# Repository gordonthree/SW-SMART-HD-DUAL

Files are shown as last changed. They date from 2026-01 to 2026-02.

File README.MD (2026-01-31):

# Heavy Duty Dual Smart Switch Node

Compact power distribution module intended to control two heavy duty high-side DC loads. The module provides eFuse protection and current monitoring for each load. Module temperature and supply voltage are also monitored. This module works with other CAN-CTL modules using the robust CAN bus interface.

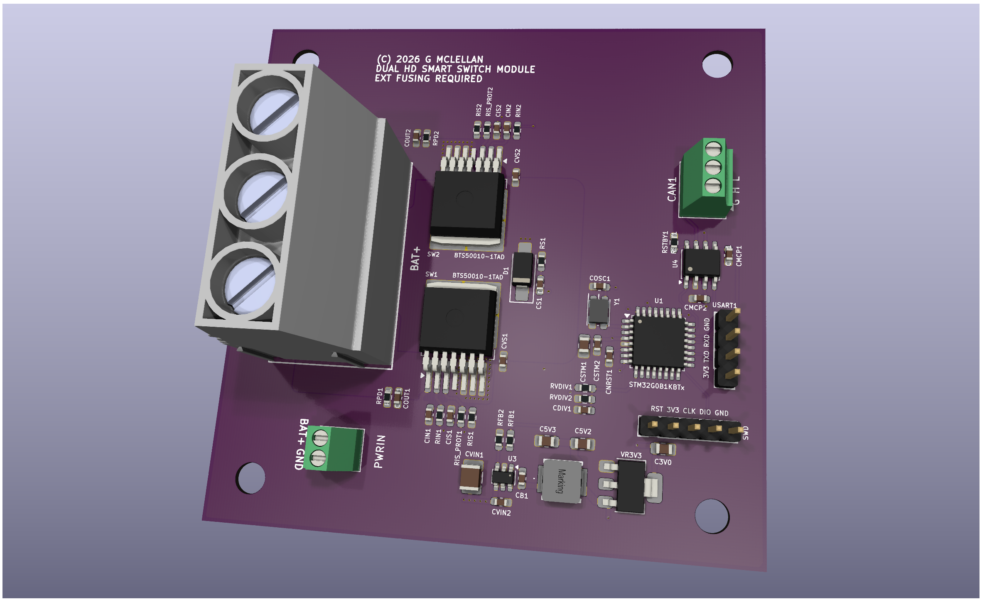
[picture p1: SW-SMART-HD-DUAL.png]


* STM32G0B1KBT 32-pin microcontroller on board
* Dual Infineon BTS50010 Profet smart switches for high side loads
* Microchip MCP2562 isolated CAN bus transceiver
* Voltage divider to monitor supply voltage
* High side switch current monitoring and diagnostics
* Three position screw terminal block for CAN bus connection
* Heavy duty terminal block connectors for power in/out
* Headers for SWD programming and USART1 debug serial port

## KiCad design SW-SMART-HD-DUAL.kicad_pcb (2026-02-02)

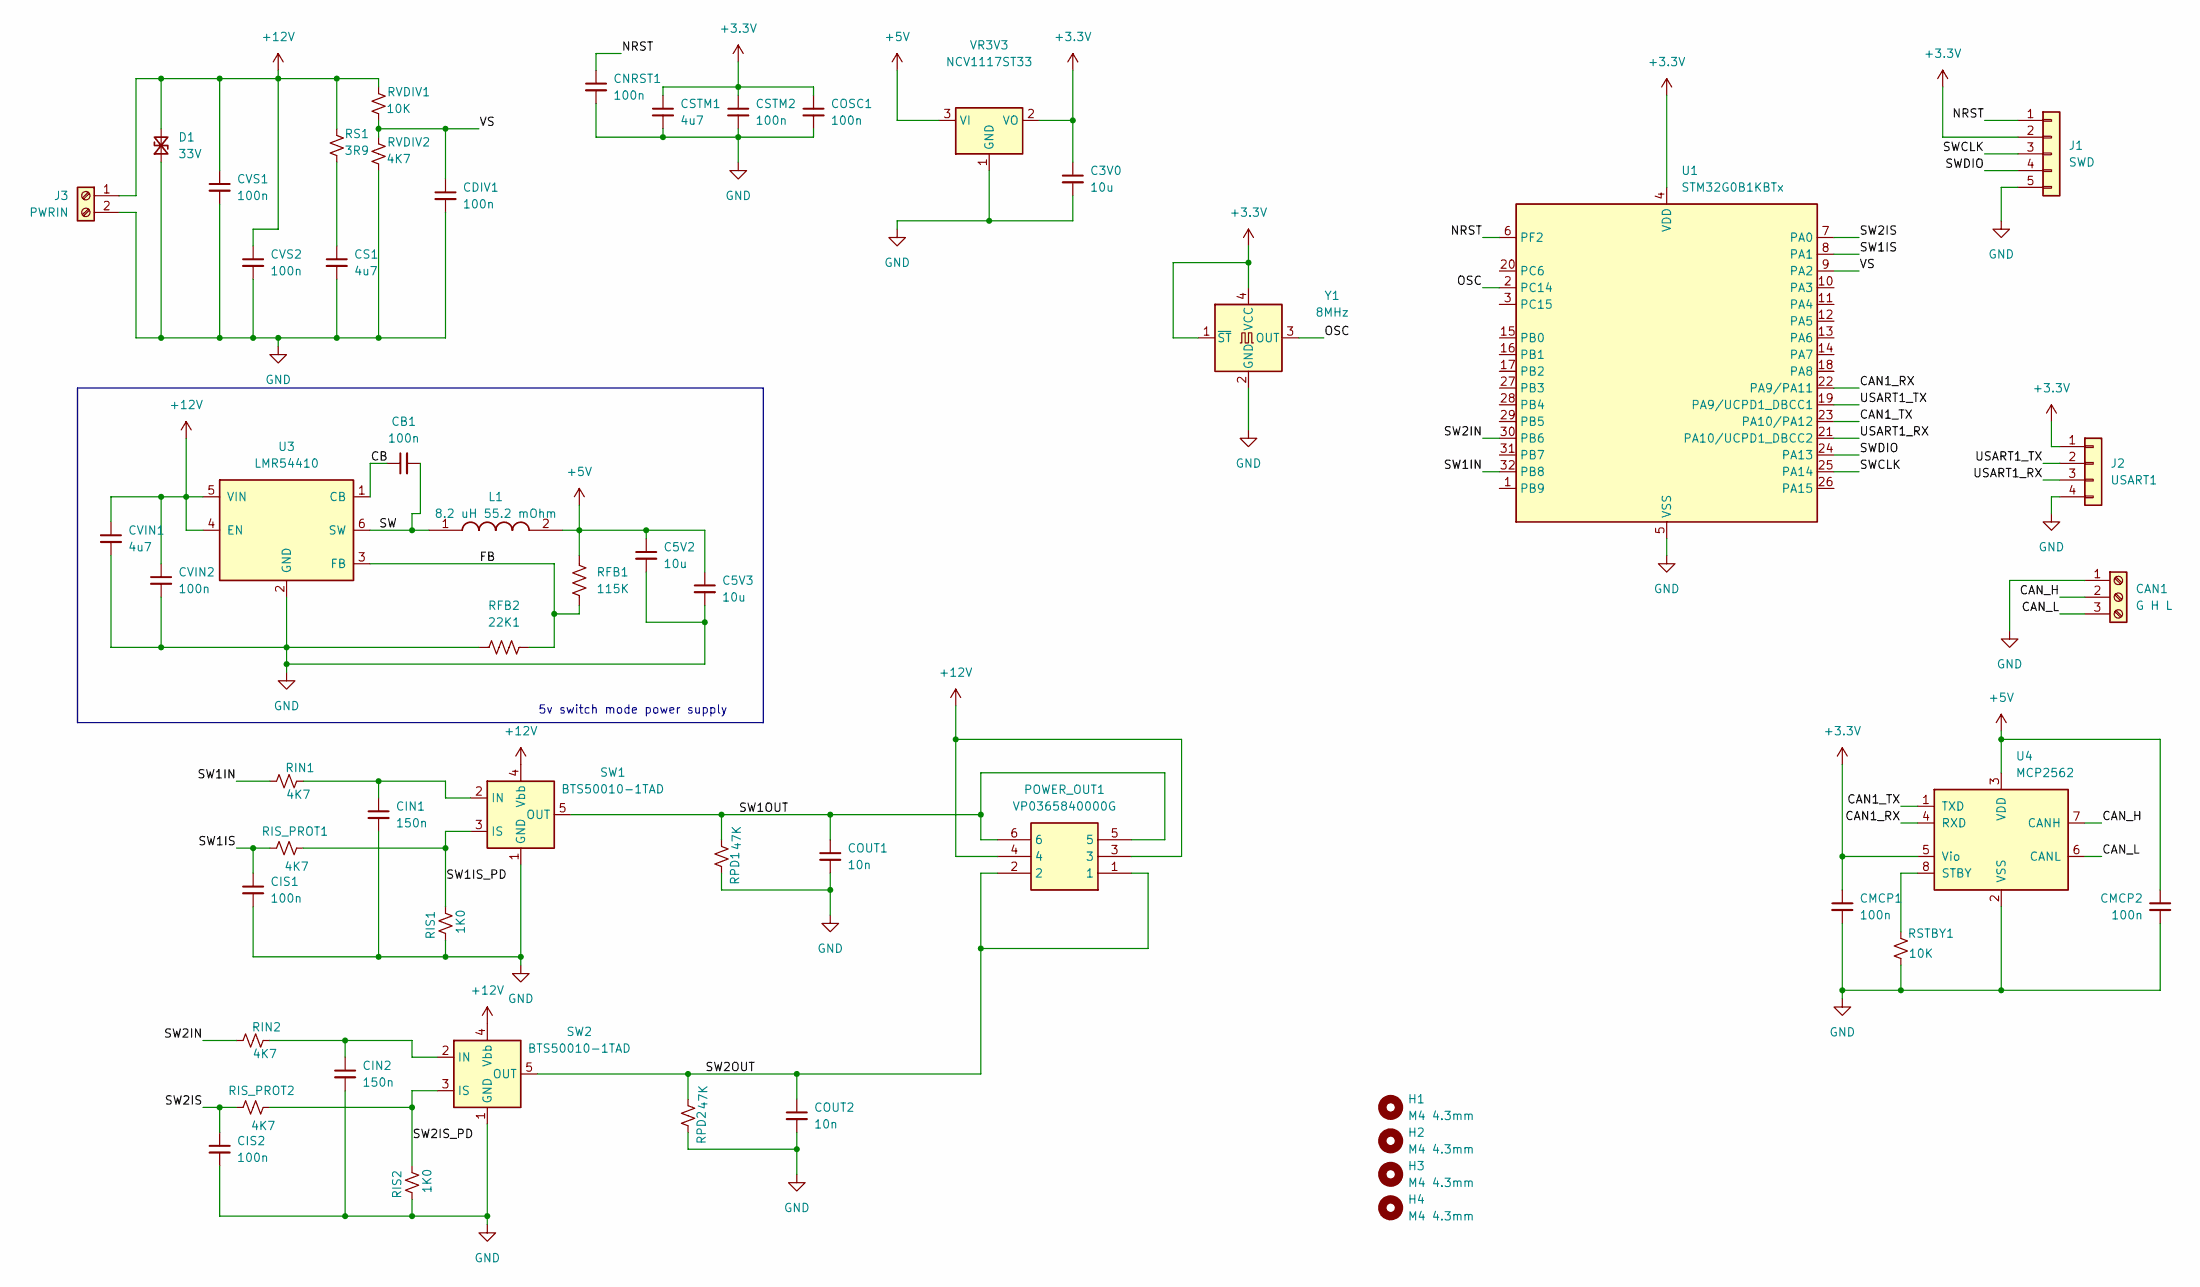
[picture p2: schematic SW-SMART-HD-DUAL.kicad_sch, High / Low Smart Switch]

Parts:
C3V0, C5V2, C5V3: 10u; C_0805_2012Metric_Pad1.18x1.45mm_HandSolder
CAN1: G H L; TerminalBlock_Phoenix_MPT-0,5-3-2.54_1x03_P2.54mm_Horizontal
CB1: 100n; C_0603_1608Metric_Pad1.08x0.95mm_HandSolder
CDIV1: 100n; C_0603_1608Metric_Pad1.08x0.95mm_HandSolder
CIN1, CIN2: 150n; C_0603_1608Metric_Pad1.08x0.95mm_HandSolder
CIS1, CIS2: 100n; C_0603_1608Metric_Pad1.08x0.95mm_HandSolder
CMCP1, CMCP2: 100n; C_0603_1608Metric_Pad1.08x0.95mm_HandSolder
CNRST1: 100n; C_0603_1608Metric_Pad1.08x0.95mm_HandSolder
COSC1: 100n; C_0603_1608Metric_Pad1.08x0.95mm_HandSolder
COUT1, COUT2: 10n; C_0603_1608Metric_Pad1.08x0.95mm_HandSolder
CS1: 4u7; C_0603_1608Metric_Pad1.08x0.95mm_HandSolder
CSTM1: 4u7; C_0805_2012Metric_Pad1.18x1.45mm_HandSolder
CSTM2: 100n; C_0603_1608Metric_Pad1.08x0.95mm_HandSolder
CVIN1: 4u7; C_1210_3225Metric_Pad1.33x2.70mm_HandSolder
CVIN2: 100n; C_0603_1608Metric_Pad1.08x0.95mm_HandSolder
CVS1, CVS2: 100n; C_0603_1608Metric_Pad1.08x0.95mm_HandSolder
D1: 33V; D_SMA_Handsoldering
H1, H2, H3, H4: M4 4.3mm; MountingHole_4.3mm_M4
J1: SWD; PinHeader_1x05_P2.54mm_Vertical
J2: USART1; PinHeader_1x04_P2.54mm_Vertical
J3: PWRIN; TerminalBlock_Phoenix_MPT-0,5-2-2.54_1x02_P2.54mm_Horizontal
L1: 8.2 uH 55.2 mOhm; SRP5030HMT2R2M; Mouser Part Number SRP5030HMT-8R2M
POWER_OUT1: VP0365840000G; Mouser Part Number 649-VP03658400J0G
RFB1: 115K; R_0603_1608Metric_Pad0.98x0.95mm_HandSolder
RFB2: 22K1; R_0603_1608Metric_Pad0.98x0.95mm_HandSolder
RIN1, RIN2: 4K7; R_0603_1608Metric_Pad0.98x0.95mm_HandSolder
RIS1, RIS2: 1K0; R_0603_1608Metric_Pad0.98x0.95mm_HandSolder
RIS_PROT1, RIS_PROT2: 4K7; R_0603_1608Metric_Pad0.98x0.95mm_HandSolder
RPD1, RPD2: 47K; R_0603_1608Metric_Pad0.98x0.95mm_HandSolder
RS1: 3R9; R_0603_1608Metric_Pad0.98x0.95mm_HandSolder
RSTBY1: 10K; R_0603_1608Metric_Pad0.98x0.95mm_HandSolder
RVDIV1: 10K; R_0603_1608Metric_Pad0.98x0.95mm_HandSolder
RVDIV2: 4K7; R_0603_1608Metric_Pad0.98x0.95mm_HandSolder
SW1, SW2: BTS50010-1TAD; TO-263-7_TabPin4
U1: STM32G0B1KBTx; LQFP-32_7x7mm_P0.8mm
U3: LMR54410; SOT-23-6
U4: MCP2562; SOIC-8_3.9x4.9mm_P1.27mm
VR3V3: NCV1117ST33; SOT-223-3_TabPin2
Y1: 8MHz; Oscillator_SMD_EuroQuartz_XO32-4Pin_3.2x2.5mm_RotB_HandSold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

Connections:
+3.3V: C3V0.1, CMCP1.1, COSC1.1, CSTM1.1, CSTM2.1, J1.2, J2.1, U1.4 (VDD), U4.5 (Vio), VR3V3.2 (VO), Y1.1 (~ST), Y1.4 (VCC)
+5V: C5V2.1, C5V3.1, CMCP2.1, L1.2, RFB1.1, U4.3 (VDD), VR3V3.3 (VI)
+12V: CVIN1.1, CVIN2.1, CVS1.1, CVS2.1, D1.2 (A2), J3.1, POWER_OUT1.3, POWER_OUT1.4, RS1.2, RVDIV1.2, SW1.4 (Vbb), SW2.4 (Vbb), U3.4 (EN), U3.5 (VIN)
/CAN1_RX: U1.22 (PA9/PA11), U4.4 (RXD)
/CAN1_TX: U1.23 (PA10/PA12), U4.1 (TXD)
/CAN_H: CAN1.2, U4.7 (CANH)
/CAN_L: CAN1.3, U4.6 (CANL)
/CB: CB1.1, U3.1 (CB)
/FB: RFB1.2, RFB2.2, U3.3 (FB)
/NRST: CNRST1.1, J1.1, U1.6 (PF2)
/OSC: U1.2 (PC14), Y1.3 (OUT)
/SW: CB1.2, L1.1, U3.6 (SW)
/SW1IN: RIN1.1, U1.32 (PB8)
/SW1IS: CIS1.1, RIS_PROT1.1, U1.8 (PA1)
/SW1IS_PD: RIS1.2, RIS_PROT1.2, SW1.3 (IS)
/SW1OUT: COUT1.1, POWER_OUT1.5, POWER_OUT1.6, RPD1.2, SW1.5 (OUT), SW1.6 (OUT), SW1.7 (OUT)
/SW2IN: RIN2.1, U1.30 (PB6)
/SW2IS: CIS2.1, RIS_PROT2.1, U1.7 (PA0)
/SW2IS_PD: RIS2.2, RIS_PROT2.2, SW2.3 (IS)
/SW2OUT: COUT2.1, POWER_OUT1.1, POWER_OUT1.2, RPD2.2, SW2.5 (OUT), SW2.6 (OUT), SW2.7 (OUT)
/SWCLK: J1.3, U1.25 (PA14)
/SWDIO: J1.4, U1.24 (PA13)
/USART1_RX: J2.3, U1.21 (PA10/UCPD1_DBCC2)
/USART1_TX: J2.2, U1.19 (PA9/UCPD1_DBCC1)
/VS: CDIV1.1, RVDIV1.1, RVDIV2.2, U1.9 (PA2)
GND: C3V0.2, C5V2.2, C5V3.2, CAN1.1, CDIV1.2, CIN1.2, CIN2.2, CIS1.2, CIS2.2, CMCP1.2, CMCP2.2, CNRST1.2, COSC1.2, COUT1.2, COUT2.2, CS1.2, CSTM1.2, CSTM2.2, CVIN1.2, CVIN2.2, CVS1.2, CVS2.2, D1.1 (A1), J1.5, J2.4, J3.2, RFB2.1, RIS1.1, RIS2.1, RPD1.1, RPD2.1, RSTBY1.1, RVDIV2.1, SW1.1 (GND), SW2.1 (GND), U1.5 (VSS), U3.2 (GND), U4.2 (VSS), VR3V3.1 (GND), Y1.2 (GND)
unnamed: CS1.1, RS1.1
unnamed: CIN1.1, RIN1.2, SW1.2 (IN)
unnamed: CIN2.1, RIN2.2, SW2.2 (IN)
unnamed: RSTBY1.2, U4.8 (STBY)

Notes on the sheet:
5v switch mode power supply

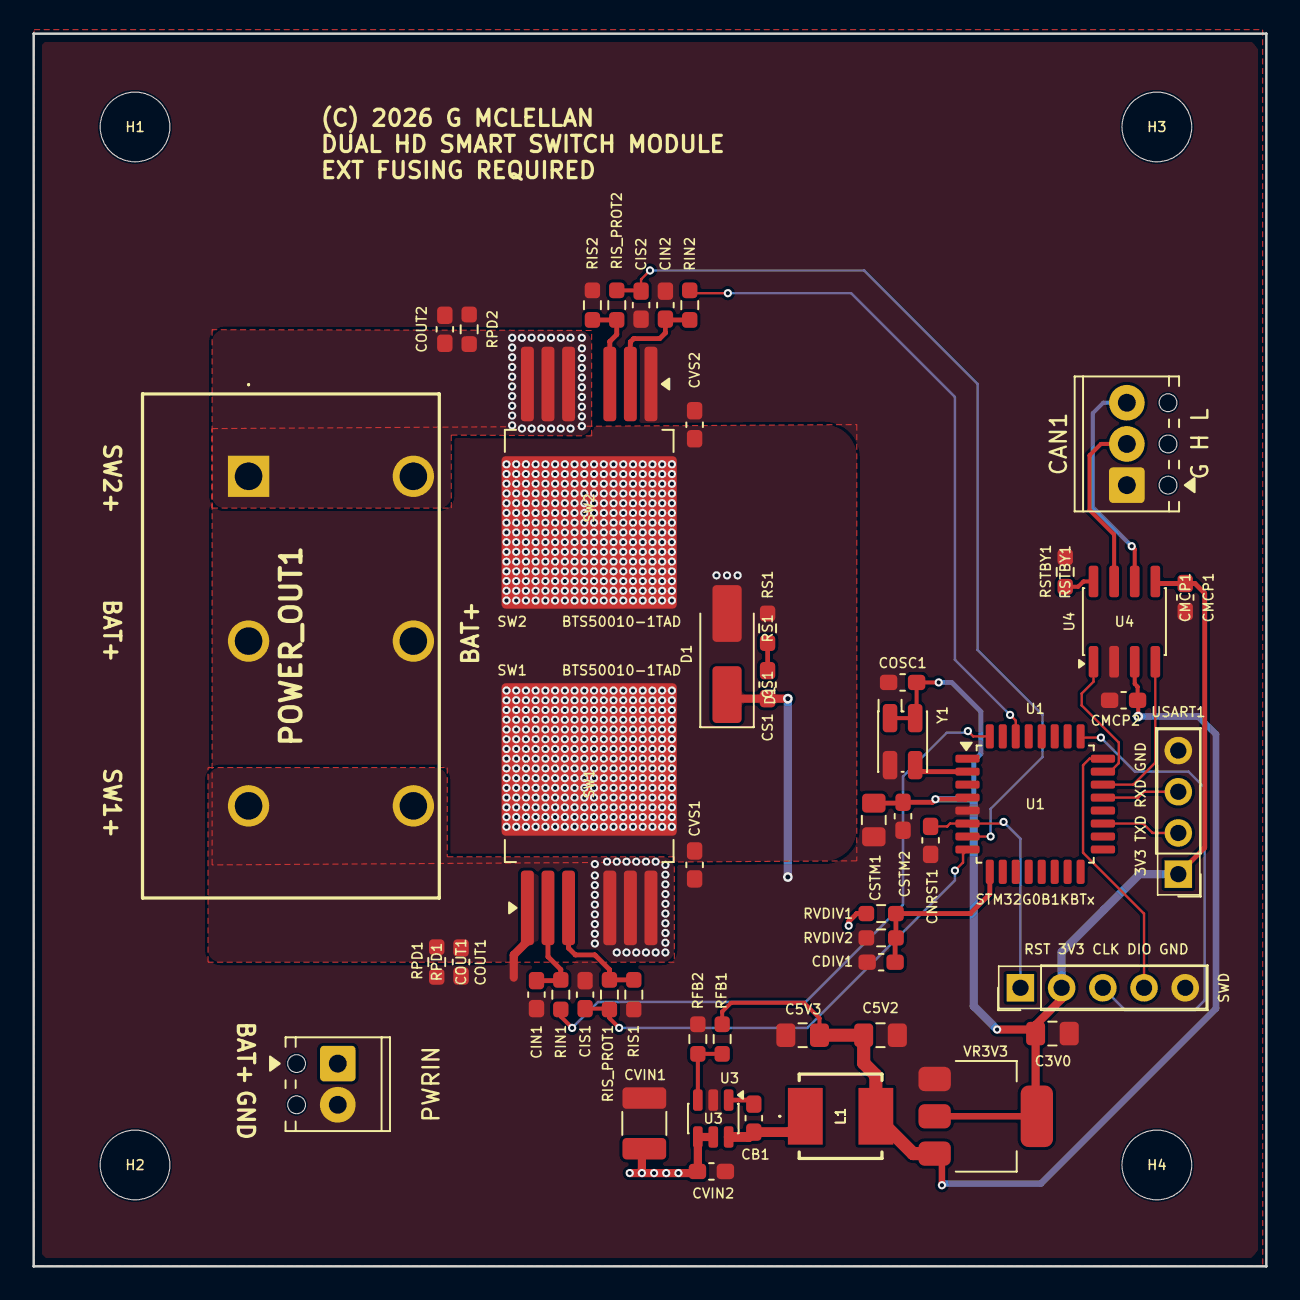
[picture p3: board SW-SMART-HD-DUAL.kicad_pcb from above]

Board: 2 copper layers, 76.0 x 76.0 mm, 54 parts (0 on the bottom side), 30 nets.

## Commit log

2026-01-30 lots of updates
    [SW-SMART-HD-DUAL.kicad_pcb, SW-SMART-HD-DUAL.kicad_sch]
2026-01-31 layout complete, drc passed
    [SW-SMART-HD-DUAL.kicad_pcb, SW-SMART-HD-DUAL.kicad_sch]
2026-02-02 added crystal osc, fixed some silkscreen issues, moved a few tracks
    [SW-SMART-HD-DUAL.kicad_pcb, SW-SMART-HD-DUAL.kicad_sch]
2026-02-02 moved osc capacitor for easier copy pasta
    [SW-SMART-HD-DUAL.kicad_sch]

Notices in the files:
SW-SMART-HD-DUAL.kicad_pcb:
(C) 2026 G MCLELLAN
